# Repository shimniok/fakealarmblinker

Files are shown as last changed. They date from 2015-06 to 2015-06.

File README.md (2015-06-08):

A fake car alarm blinker circuit based on the venerable 555 timer in astable mode.

In the schematic I set up a frequency and duty cycle that I personally prefer
(around 1-2Hz, 80% OFF / 20% ON duty cycle (555 is sinking current from LED)
but you can easily change the R1/R2/C1 values using various 555 timer calculators
like [this one](http://www.ohmslawcalculator.com/555-astable-calculator)

The project is designed to fit into a Hammond 1555Q box [[pdf](http://www.hammondmfg.com/pdf/1551PFL.pdf)] which is a small flanged-mount box, so it'll be easy to install into your vehicle.

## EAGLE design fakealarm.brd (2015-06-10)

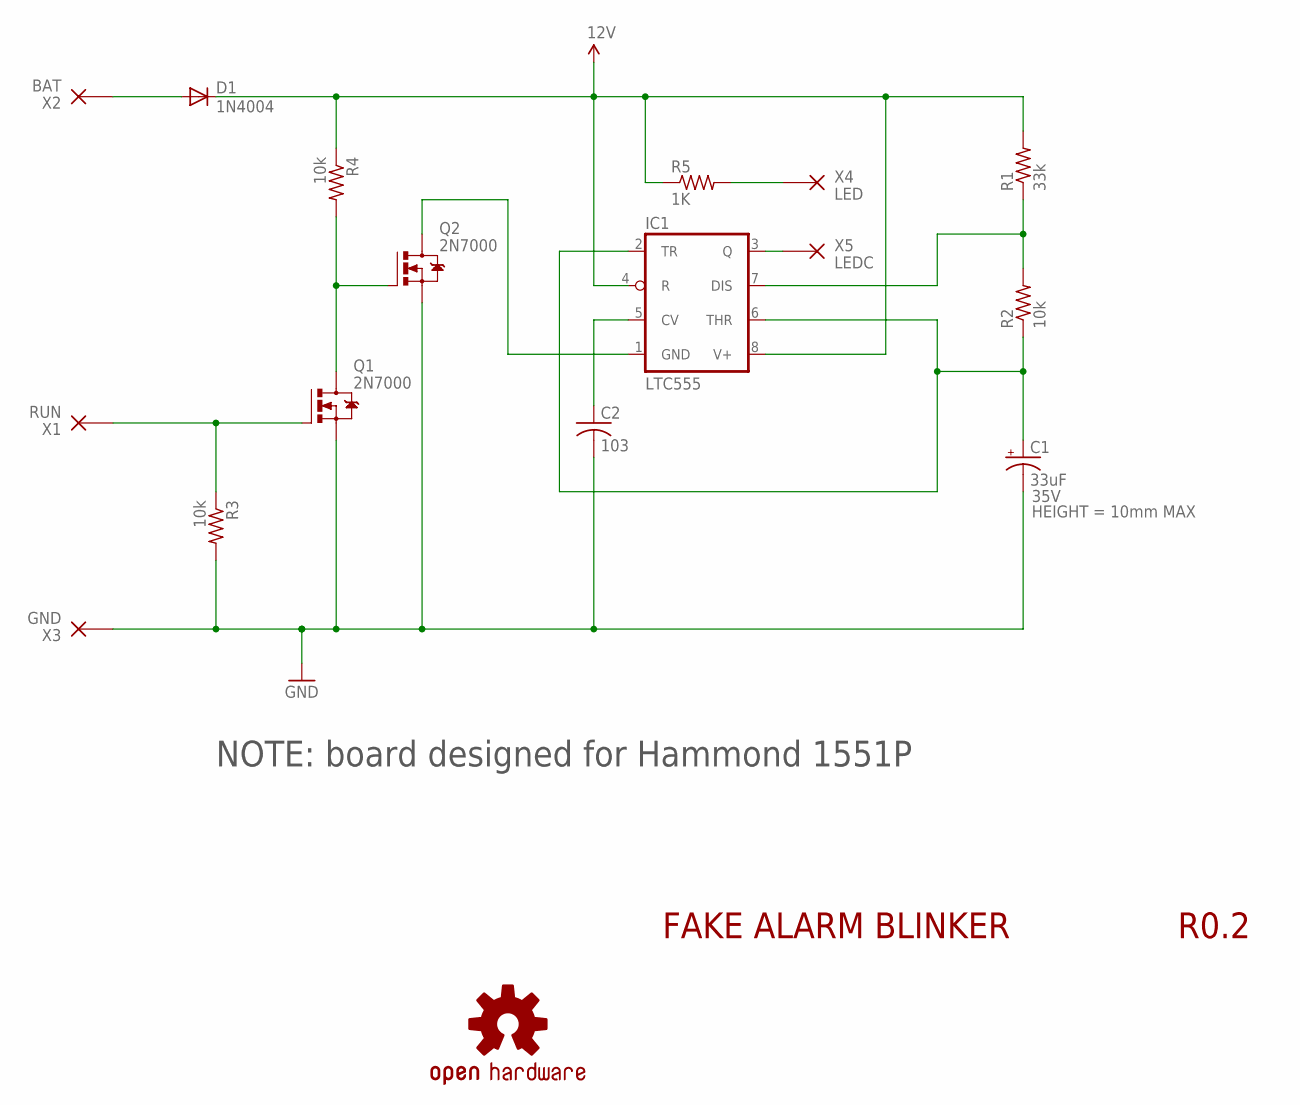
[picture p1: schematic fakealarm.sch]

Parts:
C1: 33uF; E2,5-6; VOLTAGE 35V
C2: 103; C050-024X044
D1: 1N4004; DO41-10
IC1: LTC555; DIL08
LOGO1: OSHW-LOGOM; OSHW-LOGO-M
Q1, Q2: 2N7000; TO92D-
R1: 33k; 0207/10
R2, R3, R4: 10k; 0207/10
R5: 1K; 0207/10
X1: RUN; PAD_14GA
X2: BAT; PAD_14GA
X3: GND; PAD_14GA
X4: LED; PAD_24GA
X5: LEDC; PAD_24GA

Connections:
12V: D1.C, IC1.4 (R), IC1.8 (V+), R1.2, R4.1, R5.1
GND: C1.-, C2.2, Q1.1 (S), Q2.1 (S), R3.2, X3.P$1
unnamed: Q1.3 (D), Q2.2 (G), R4.2
unnamed: Q1.2 (G), R3.1, X1.P$1
unnamed: IC1.7 (DIS), R1.1, R2.2
unnamed: C1.+, IC1.2 (TR), IC1.6 (THR), R2.1
unnamed: IC1.1 (GND), Q2.3 (D)
unnamed: D1.A, X2.P$1
unnamed: C2.1, IC1.5 (CV)
unnamed: R5.2, X4.P$1
unnamed: IC1.3 (Q), X5.P$1

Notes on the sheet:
FAKE ALARM BLINKER
R0.2
NOTE: board designed for Hammond 1551P

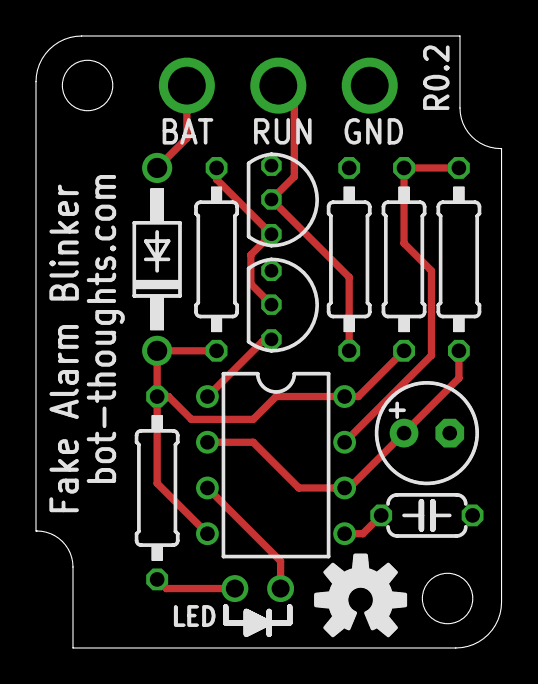
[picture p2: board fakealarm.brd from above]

Board: 2 copper layers, 25.9 x 34.0 mm, 17 parts (0 on the bottom side), 11 nets.

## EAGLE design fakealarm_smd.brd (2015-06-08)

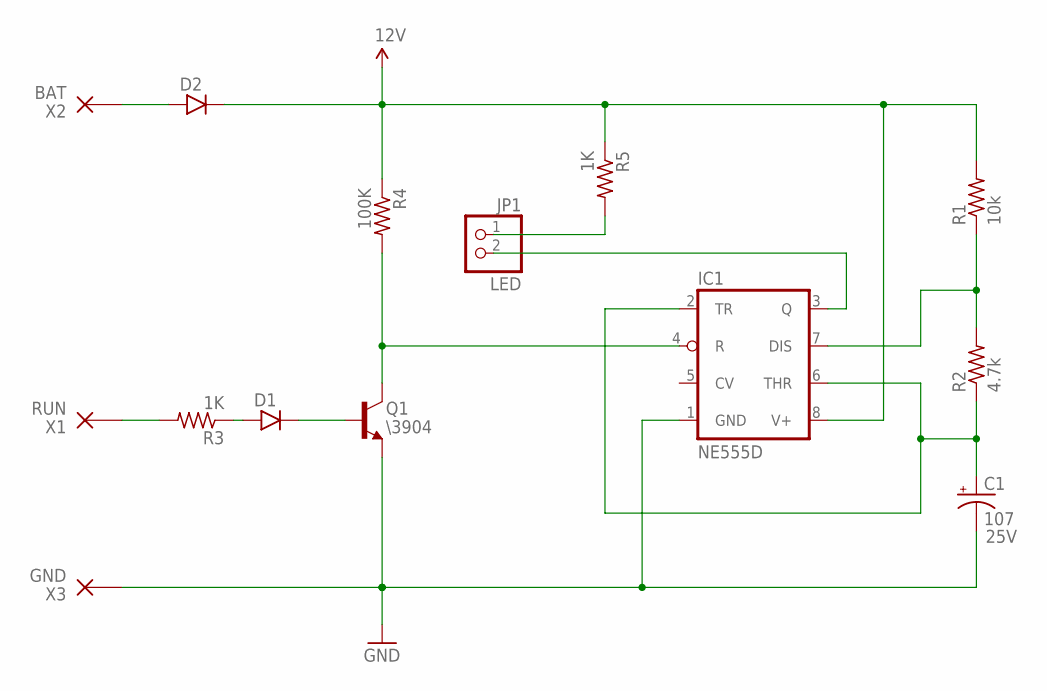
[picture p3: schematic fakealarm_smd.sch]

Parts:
C1: 107; PANASONIC_C; VOLTAGE 25V
D1, D2: DIODE_SOD123FL; SOD123FL
IC1: NE555D; SO08
JP1: LED; 1X02-S
Q1: \3904; SOT-23
R1: 10k; R0603
R2: 4.7k; R0603
R3, R5: 1K; R0603
R4: 100K; R0603
X1: RUN; PAD_14GA
X2: BAT; PAD_14GA
X3: GND; PAD_14GA

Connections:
12V: D2.C, IC1.8 (V+), R1.2, R4.1, R5.1
GND: C1.-, IC1.1 (GND), Q1.2 (E), X3.P$1
unnamed: D1.A, R3.1
unnamed: D1.C, Q1.3 (B)
unnamed: IC1.7 (DIS), R1.1, R2.2
unnamed: C1.+, IC1.2 (TR), IC1.6 (THR), R2.1
unnamed: R3.2, X1.P$1
unnamed: D2.A, X2.P$1
unnamed: JP1.1, R5.2
unnamed: IC1.3 (Q), JP1.2
unnamed: IC1.4 (R), Q1.1 (C), R4.2

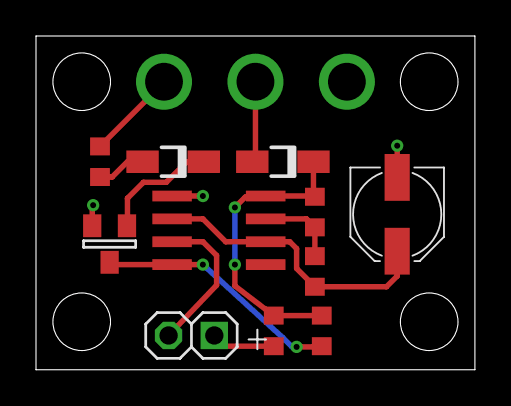
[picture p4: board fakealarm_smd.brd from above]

Board: 2 copper layers, 24.4 x 18.5 mm, 14 parts (0 on the bottom side), 11 nets.

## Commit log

2015-06-08 Added 10nF (0.01uF) bypass on CV, shrank board, moved components around a little
    [fakealarm.brd, fakealarm.sch]
2015-06-08 added oshw logo, minor silk layout tweaks
    [fakealarm.brd, fakealarm.sch]
2015-06-08 Generated silk, added enclosure info to schematic
    [fakealarm.brd, fakealarm.sch]
2015-06-08 Changed Documentation layer visibility to show enclosure info
    [fakealarm.brd]
2015-06-08 fixed drill size for 2nd hole
    [fakealarm.brd]
2015-06-08 redesigned for hammond 1551P (taller enclosure), respec'ed 33uF cap height and voltage, added documentation for max board height' '
    [fakealarm.brd, fakealarm.sch]
2015-06-08 added gerbers
    [fakealarm.drills.xln]
2015-06-08 replaced NPN with N-channel MOSFET tied to power, replaced 100k rst with 10k
    [fakealarm.sch]
2015-06-09 Revised switch to use two mosfets to switch entire 555, revised layout, silk, added enclosure info to board
    [fakealarm.brd, fakealarm.sch]
2015-06-09 Layout tweaks on board and schematic. Added reverse protection diode
    [fakealarm.brd, fakealarm.sch]
2015-06-10 generated silk
    [fakealarm.brd]
2015-06-10 revised q2 layout
    [fakealarm.sch]
2015-06-15 Updated gerbers
    [fakealarm.drills.xln]

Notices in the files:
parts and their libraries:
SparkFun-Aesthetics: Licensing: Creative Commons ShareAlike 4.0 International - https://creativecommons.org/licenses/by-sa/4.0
